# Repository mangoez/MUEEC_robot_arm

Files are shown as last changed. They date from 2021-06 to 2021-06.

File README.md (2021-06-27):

# MUEEC_robot_arm
Welcome!
If you are here you either have landed on my nerd turf and/or you are looking for the code to control a robot arm. 
In summary, this is operated by geometrically calculated inverse kinematics code for both MATLAB and Arduino with the simulation done in MATLAB for a 3DOF serial arm. This is all controlled by a single arduino and runs in real time with decent precision of the end effector. 

In the folder there is also code to calibrate and test the Wii nunchuck as well as the servos for your individual projects.

## Geometrically calculated Inverse Kinematics
Given the position of the end effector calculate the angles of each individual servo such that the end effector is exactly at the target position
The functions are calculated by projecting the 3D robot arm onto a 2D plane to simplify the problem.

This is the paper I based it off of, note I said BASED because some of the equations are WRONG...yeah...
https://www.researchgate.net/publication/328583527_A_Geometric_Approach_to_Inverse_Kinematics_of_a_3_DOF_Robotic_Arm

* base = angle of first / base servo
* shoulder = angle of second servo
* elbow = angle of the third servo

## MATLAB simulation code:
The 3 joints are simulated and plotted in 3D to make sure the geometric solution is exact.  

## Arduino code:
Necessary libraries 
* nunchuck library: NintendoExtensionCtrl
* servo speed library: VarSpeedServo

A wii nunchuck is used to dictate the position in 3D to be converted into angles for the servo

### robot_control_geometric
Is the actual program used to calculate the servo angles in order to position the end effector in 3D space. 

### nunchuck_only
Connect and print the values from the nunchuck to test the connection and values of the joystick _ buttons

### set_servo_range
This is designed to be used with the calibrating tool we provided that gives you 5 degree resolution of where your servo is.
Use that and this program to set the minimum and maximum values of your servo which correspond to 0 - 180 degrees for each individual servo. 

### servo_test 
Just checks the connection and literally run the servo between two positions, introduces the package for variable speed control of the servo.

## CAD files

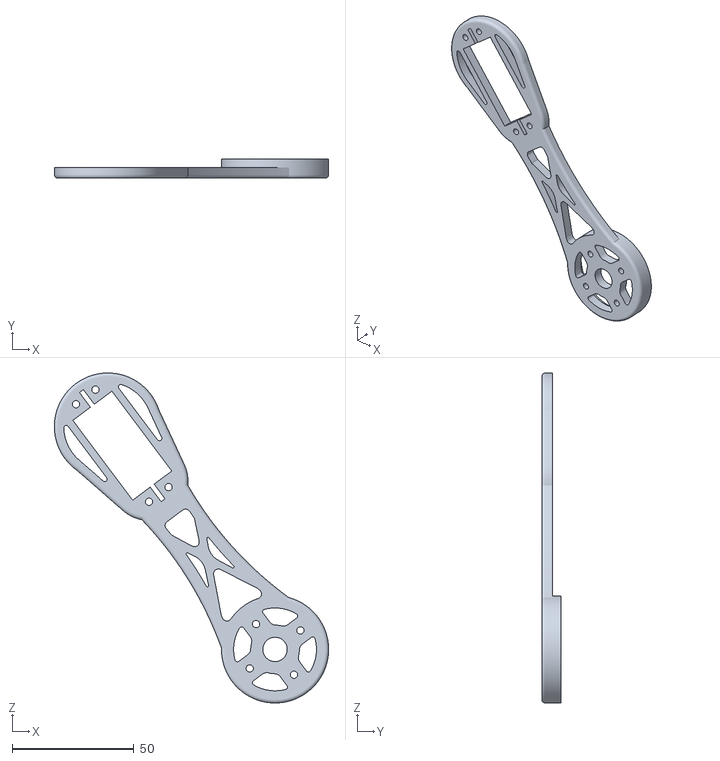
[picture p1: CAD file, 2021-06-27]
STL files/Robot components/arm_M3.stl
112.6 x 8.00 x 135.5

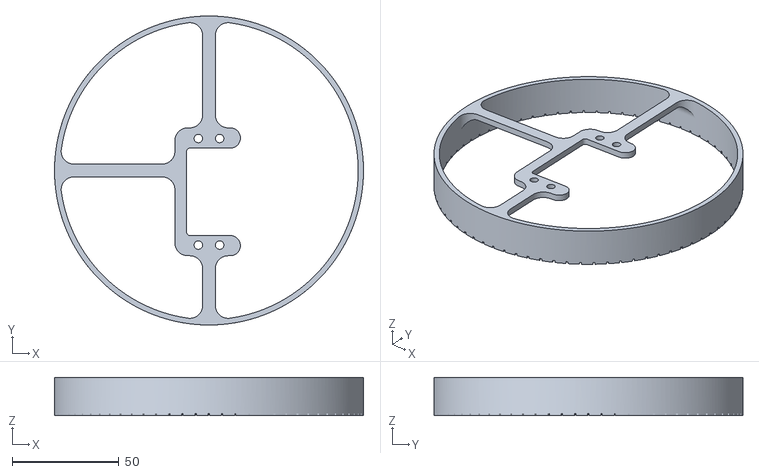
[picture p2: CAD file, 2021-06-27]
STL files/Servo calibration/Sevo_protractor_HX5010_thin_v1.stl
145.0 x 145.0 x 18.0

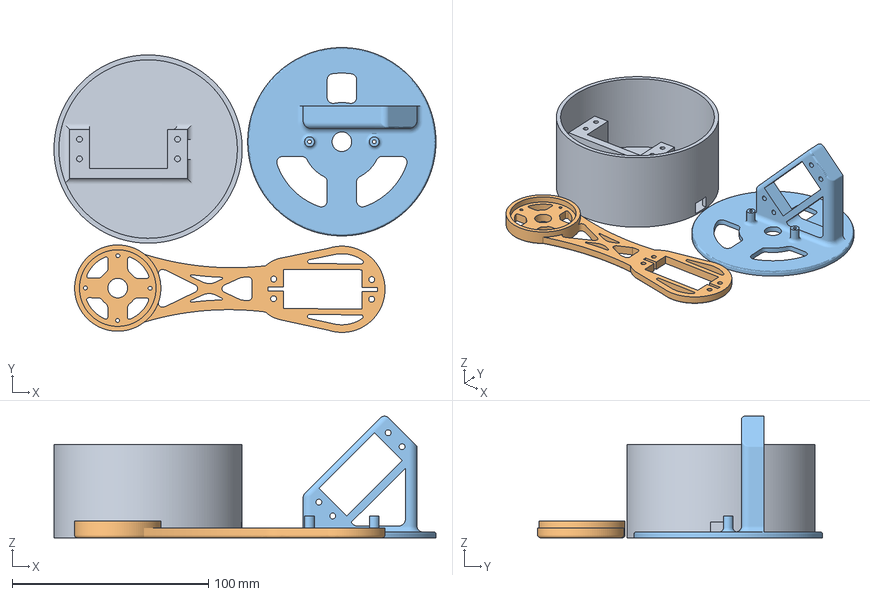
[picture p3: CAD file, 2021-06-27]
STL files/Robot components/BASE_CAP_ARM.3mf
194.8 x 145.3 x 62.0 mm
base.stl
arm.stl
cap.stl

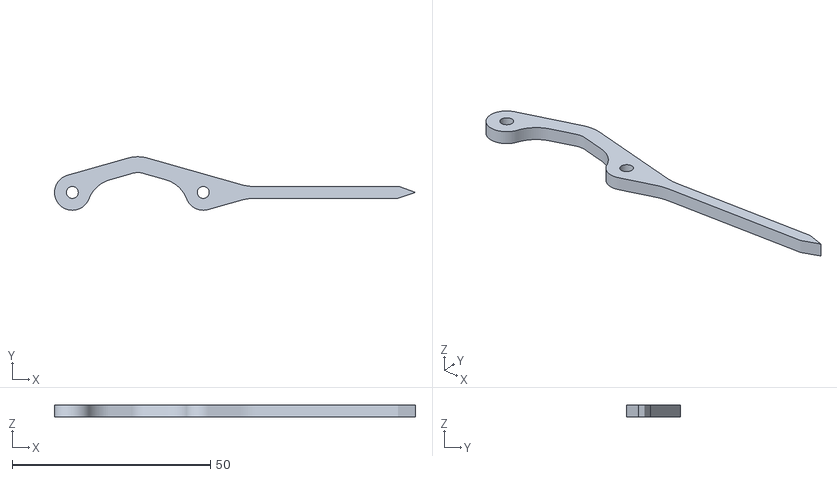
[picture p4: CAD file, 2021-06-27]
STL files/Servo calibration/Servo_arm_3mm_v1.stl
91.0 x 13.5 x 3.00

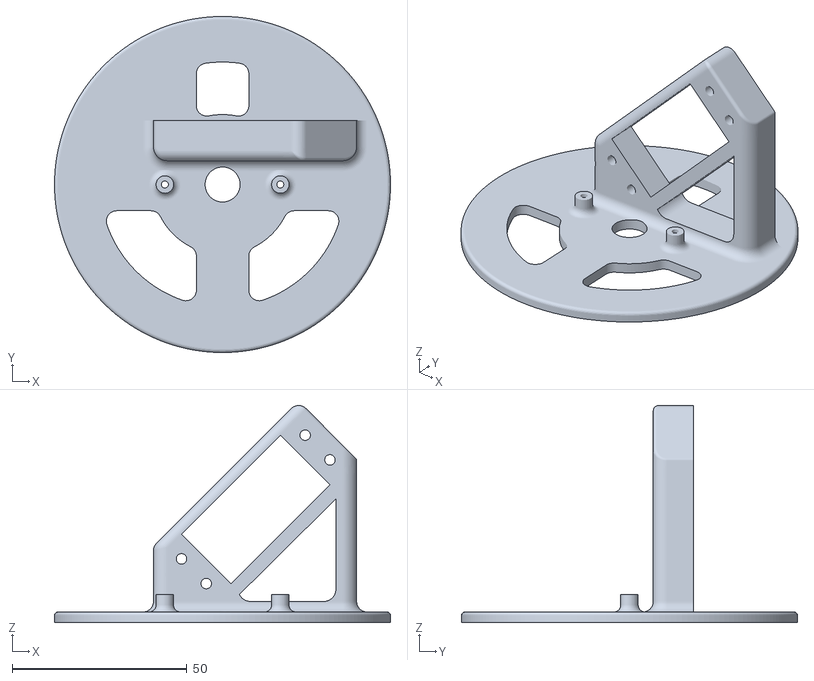
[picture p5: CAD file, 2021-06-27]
STL files/Robot components/cap.stl
96.0 x 96.0 x 62.0

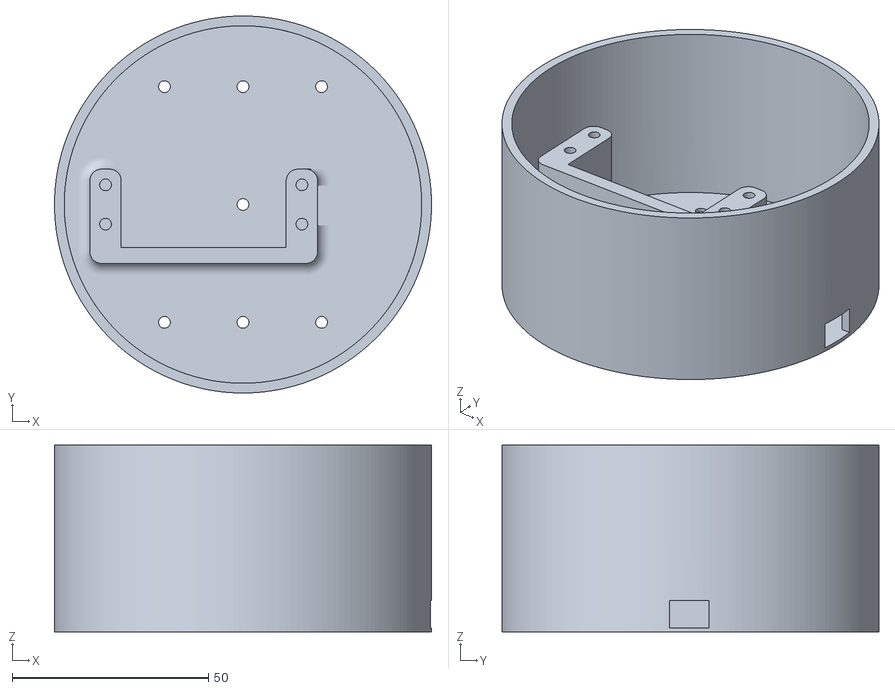
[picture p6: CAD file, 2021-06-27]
STL files/Robot components/base.stl
96.0 x 96.0 x 47.5

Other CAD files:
STL files/Robot components/arm.stl

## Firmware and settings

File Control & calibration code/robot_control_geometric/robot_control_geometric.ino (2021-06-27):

#include <VarSpeedServo.h> // To control the speed of our servos
#include <NintendoExtensionCtrl.h> // To use the hacked nunchuck controller

// Initiate some objects
Nunchuk nunchuk;
VarSpeedServo servo1;  
VarSpeedServo servo2;  
VarSpeedServo servo3;  

// Initiate the values
// Distance away from the origin of the second motor in meters
double a0 = 0.017; 
double d0 = 0.086;

// Length of the arms in meters
double d1 = 0.115;
double d2 = 0.115;

// Offsets to make things work due to the way the servo arms attach onto the servos
// there are only fixed positions you can have, meaning we need to tweak them to make it more accurate
// These are in degrees
int offset_shoulder = 13;
int offset_elbow = 3;

// Step size and servo speed
double stp = 0.0009;
int servo_v = 100;

// Initial position in meters
double x = 0.1;
double y = 0;
double z = 0.1;

// Values with the tweaks added
double xval = x + a0;
double yval = y;
double zval = z - d0;

// The rotations the servos need to make in radians
double r1;
double r2;
double r3;


// Calulation functions
double base(double x, double y){
  return atan(y/(x-a0)); 
}

double r(double x, double y, double z){
  return sqrt(pow(x-a0+a0*cos(base(x, y)),2) + pow(y+(a0*sin(base(x, y))),2) + pow(z,2));
}

double elbow(double x, double y, double z){  
  return acos((pow(r(x, y, z),2)-pow(d1,2)-pow(d2,2))/(2*d1*d2));
}

double shoulder(double x, double y, double z){
  return asin(z/r(x, y, z)) + atan((d2*sin(elbow(x, y, z))) / (d1+(d2*cos(elbow(x, y, z)))));
}


// Time to run this baby!
void setup() {
  // Start the serial connection
  Serial.begin(115200);
  Serial.setTimeout(3);

  // Start the nunchuck to run and make sure it's connected
  nunchuk.begin();
  while (!nunchuk.connect()) {
    Serial.println("Nunchuk not detected!");
    delay(1000);
  }

  // Attach my servos with the calibrated values
  servo1.attach(3, 510, 2415); 
  servo2.attach(5, 566, 2365); 
  servo3.attach(6, 678, 2475); 

  // Calculate the angles the servos will need to rotate based on the calibrated values
  // This is for the initial position
  r1 = map(base(xval, yval) * (180/PI), 0, 180, 510, 2500);
  r2 = map(shoulder(xval, yval, zval) * (180/PI), 0, 180, 2500, 570);
  r3 = map(elbow(xval, yval, zval) * (180/PI), 0, 180, 2480, 520);

  // Convert the offsets we had into adjustments in number of PWMs 
  int offset_shoulder_adj = map(offset_shoulder, 0, 180, 570, 2500);
  int offset_elbow_adj = map(offset_elbow, 0, 180, 520, 2480);

  // Send the information to the servos
  servo1.write(r1, 20, false); 
  servo2.write(r2 + offset_shoulder, 20, false); 
  servo3.write(r3 + offset_elbow, 20, false);

  // Print them all out
  Serial.println("r = " + String(r(xval, yval, zval)) +
                 "  base = " + String(base(xval, yval) * (180/PI)) + 
                 "  shoulder = " + String(shoulder(xval, yval, zval) * (180/PI)) + 
                 "  elbow = " + String(elbow(xval, yval, zval) * (180/PI)));
}


void loop() { 
  boolean success = nunchuk.update();  // Get new data from the controller
  
  if(success == true) {  // We have new data!
    nunchuk.update();
    
    int joy_x = nunchuk.joyX();
    int joy_y = nunchuk.joyY();
    int joy_c = nunchuk.buttonC();
    int joy_z = nunchuk.buttonZ();
    int servo_v = 30;

    // According to the controller value, adjust the position of the end effect in the 3D space
    if (joy_x < 128){
      x = x - stp;
    }

    if (joy_x > 128){
      x = x + stp;
    }

    if (joy_y > 128){
      y = y + stp;
    }

    if (joy_y < 128){
      y = y - stp;
    }

    if (joy_c) {
      z = z + stp;
    }

    if (joy_z) {
      z = z - stp;
    }

    xval = x + a0;
    yval = y;
    zval = z - d0;

    // Based on the new 3D position, calculate the angles needed to get there
    r1 = map(base(xval, yval) * (180/PI), 0, 180, 0, 180);
    r2 = map(shoulder(xval, yval, zval) * (180/PI), 0, 180, 180, 0);
    r3 = map(elbow(xval, yval, zval) * (180/PI), 0, 180, 180, 0);
  
    servo1.write(r1, servo_v, false); 
    servo2.write(r2, servo_v, false); 
    servo3.write(r3, servo_v, false);

    Serial.println("x = " + String(x) + 
                   ", y = " + String(y) + 
                   ", z = " + String(z) + 
                   "    " + 
                   "r1 = " + String(r1) + 
                   ", r2 = " + String(r2) + 
                   ", r3 = " + String(r3));
  }
}

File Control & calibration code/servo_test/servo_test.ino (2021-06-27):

#include <VarSpeedServo.h> // Variable speed control for servo

// Initiate servo objects
VarSpeedServo servo1;  
VarSpeedServo servo2;  
VarSpeedServo servo3;  

// Attach them, this is just a simple test so we are no calibrating them
// just making sure they are connected
void setup() {
  servo1.attach(3); 
  servo2.attach(5); 
  servo3.attach(6); 
} 

// What this will do is loop between two different positions for each servo at a specified speed
void loop() {
  servo1.write(90, 20, false);  
  servo2.write(90, 20, false); 
  servo3.write(90, 20, false);  
  delay(2500);
  servo1.write(0, 20, false); 
  servo2.write(0, 20, false);
  servo3.write(0, 20, false);
  delay(2500);  
}
